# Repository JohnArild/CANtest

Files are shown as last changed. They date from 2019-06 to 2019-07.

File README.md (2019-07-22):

# CANtest

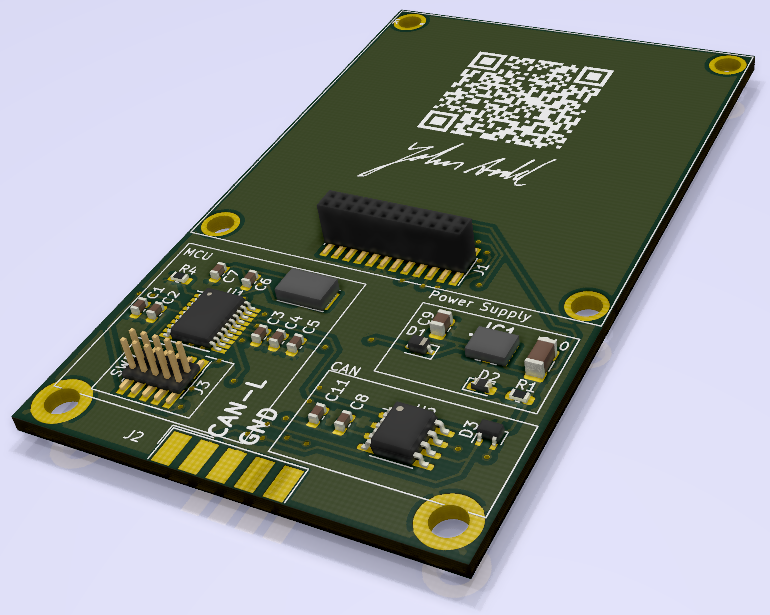
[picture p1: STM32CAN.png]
PCB Render


This project is created to test CAN functionality on STM32
For initial testing, STM32F103C8T6 (Blue Pill) was used.
New board is designed and ordered with STM32F042F6P6. (found in folder kiCad.)

Code is still a mess and just for testing.

Released under BSD License, see file named LICENSE

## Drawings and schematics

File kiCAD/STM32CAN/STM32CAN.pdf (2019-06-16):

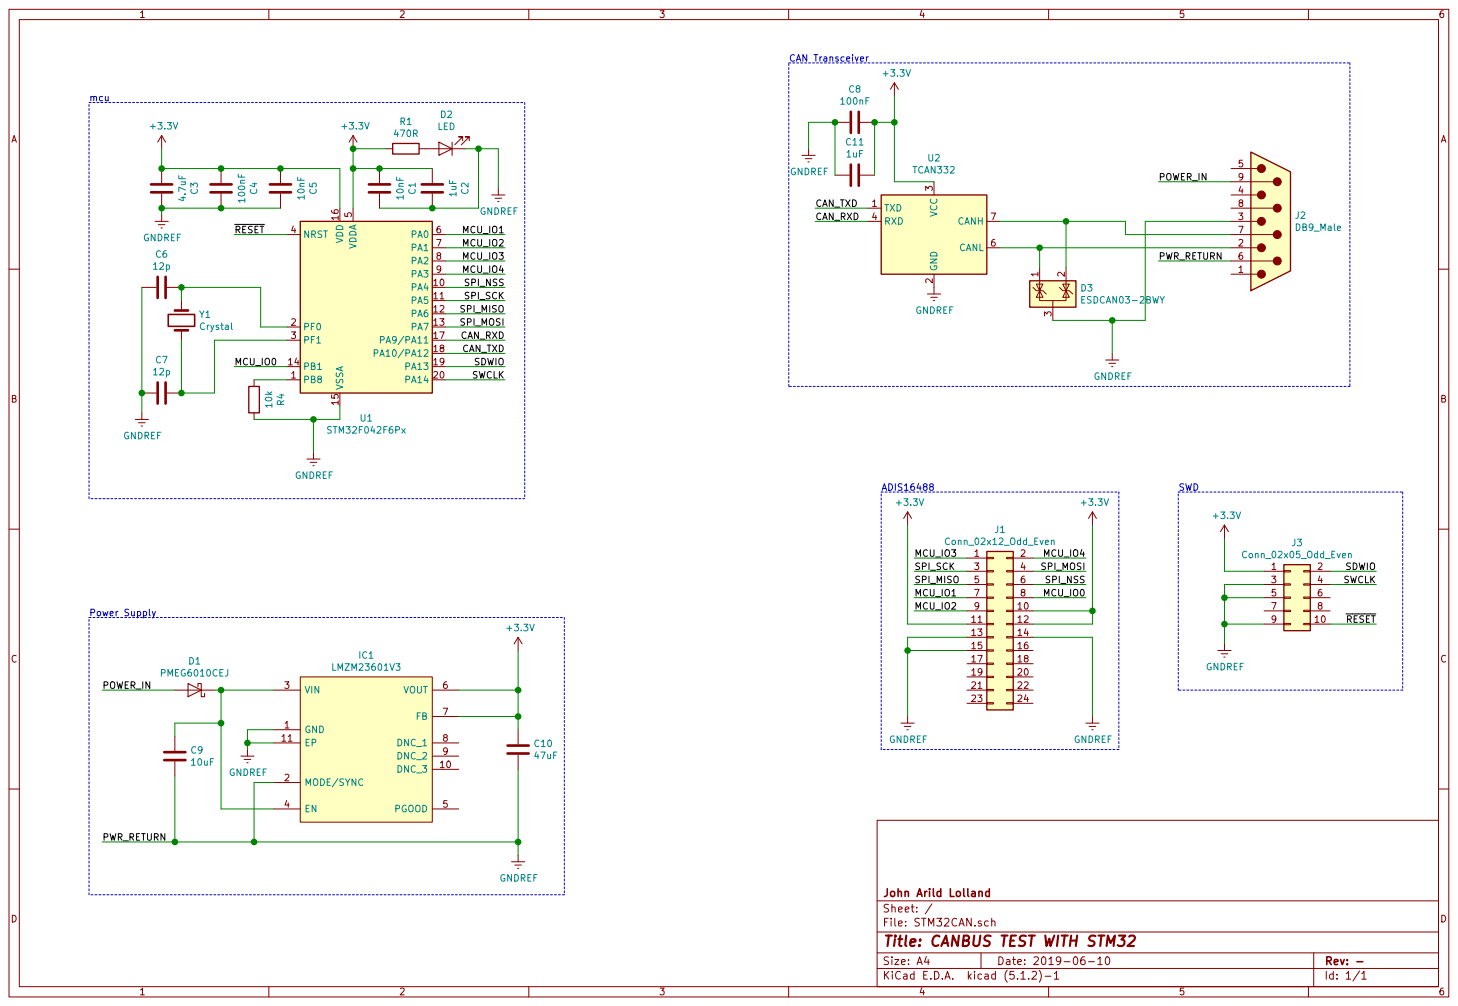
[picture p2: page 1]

3 RXD 4 CANL 6 CANH 7 U2 GNDREF TCAN332 C8

15 | 16
17 | 18

File: STM32CAN.sch Sheet: / John Arild Lolland

Id: 1/1 Title: CANBUS TEST WITH STM32

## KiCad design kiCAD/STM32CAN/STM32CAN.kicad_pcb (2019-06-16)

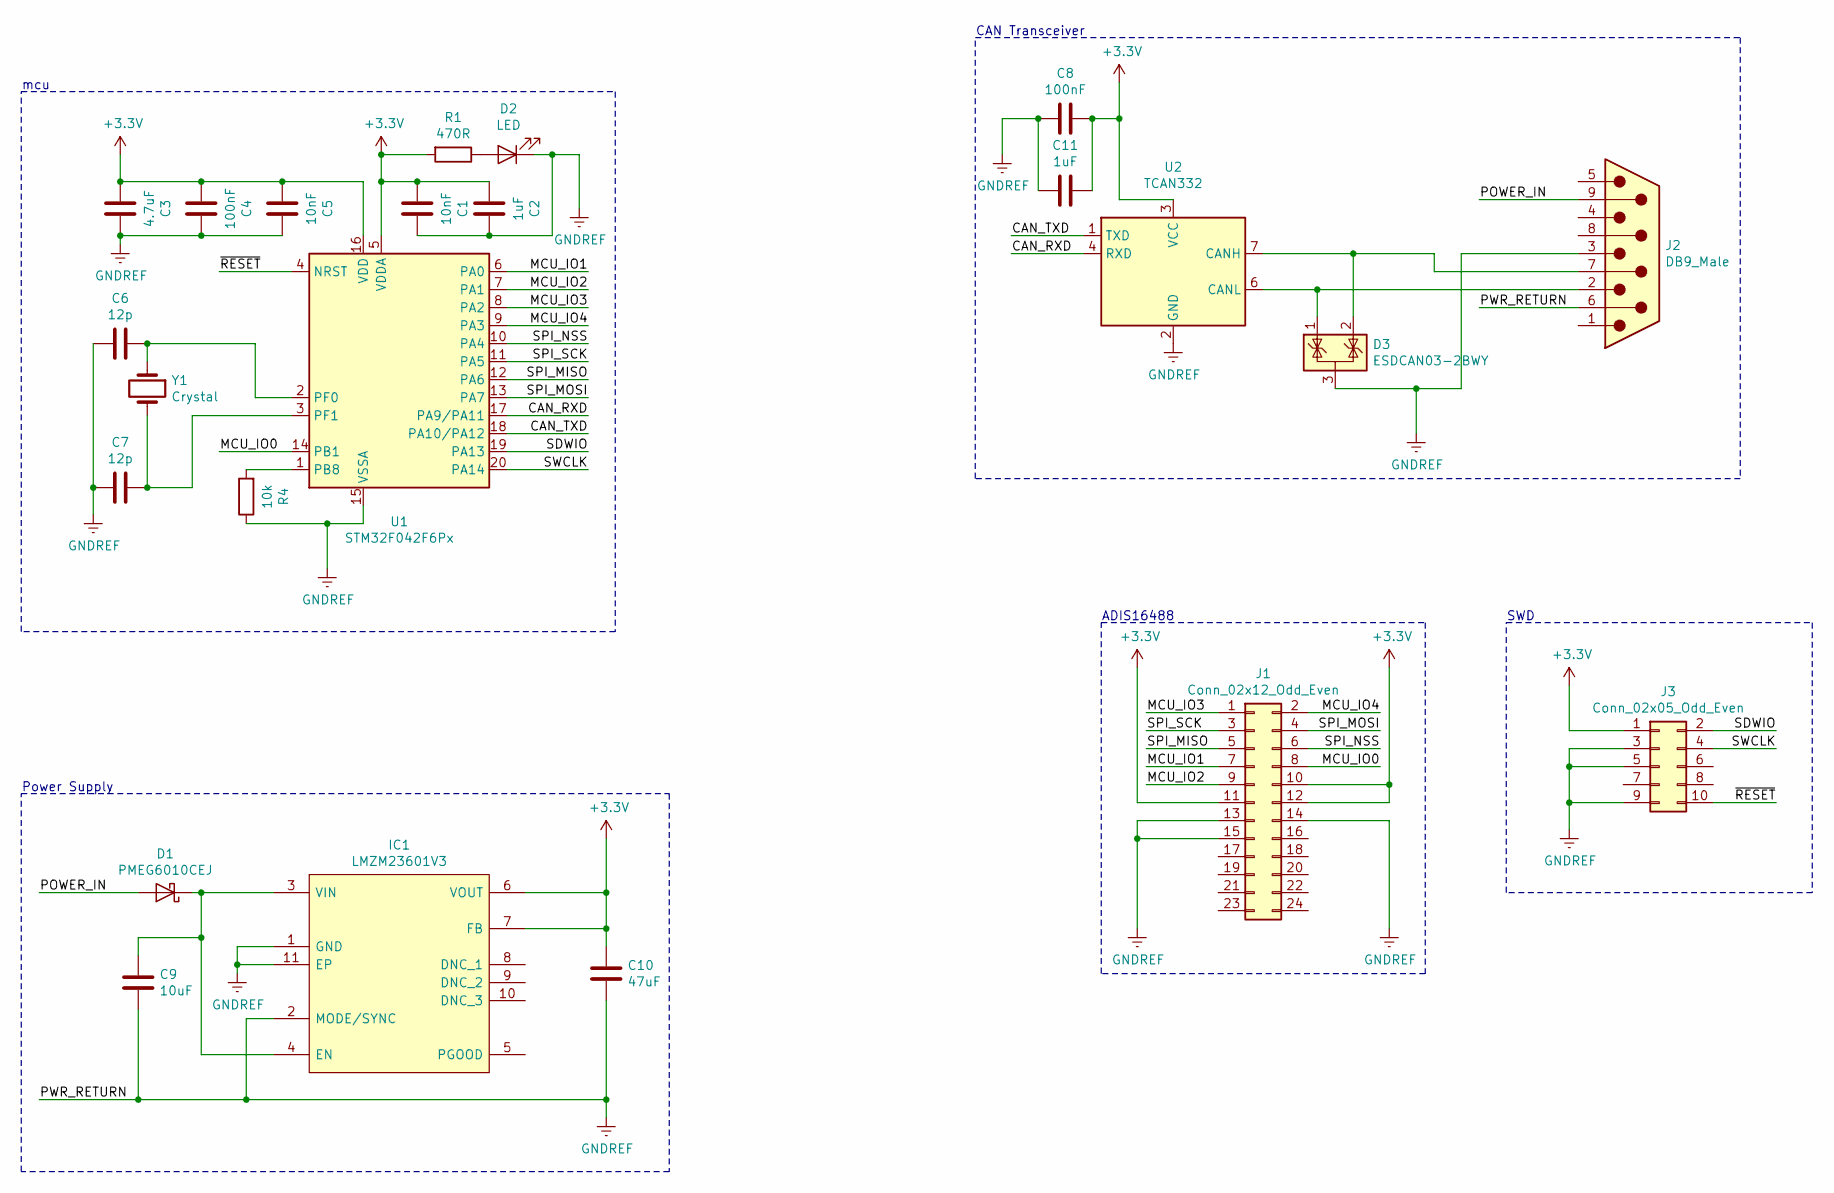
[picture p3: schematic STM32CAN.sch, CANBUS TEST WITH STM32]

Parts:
C1, C5: 10nF; C_0603_1608Metric
C2, C11: 1uF; C_0603_1608Metric
C3: 4.7uF; C_0603_1608Metric
C4, C8: 100nF; C_0603_1608Metric
C6, C7: 12p; C_0603_1608Metric
C9: 10uF; C_0805_2012Metric
C10: 47uF; C_1206_3216Metric
D1: PMEG6010CEJ; D_SOD-323
D2: LED; D_0603_1608Metric
D3: ESDCAN03-2BWY; SOT-323_SC-70
IC1: LMZM23601V3; LMZM23601V5SILR; Mouser Part Number 595-LMZM23601V5SILT
J1: Conn_02x12_Odd_Even; PinHeader_2x12_P1.27mm_Vertical_SMD
J2: DB9_Male; DSUB-9_Male_Horizontal_P2.77x2.54mm_EdgePinOffset9.40mm
J3: Conn_02x05_Odd_Even; PinHeader_2x05_P1.27mm_Vertical_SMD
R1: 470R; R_0603_1608Metric
R4: 10k; R_0603_1608Metric
U1: STM32F042F6Px; TSSOP-20_4.4x6.5mm_P0.65mm
U2: TCAN332; SOIC-8_3.9x4.9mm_P1.27mm
Y1: Crystal; 7A8000MAAET

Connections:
+3V3: C1.2, C2.2, C3.2, C4.2, C5.2, C8.1, C10.1, C11.1, IC1.6 (VOUT), IC1.7 (FB), J1.10, J1.11, J1.12, J3.1, R1.2, U1.5 (VDDA), U1.16 (VDD), U2.3 (VCC)
/CAN_RXD: U1.17 (PA9/PA11), U2.4 (RXD)
/CAN_TXD: U1.18 (PA10/PA12), U2.1 (TXD)
/MCU_IO0: J1.8, U1.14 (PB1)
/MCU_IO1: J1.7, U1.6 (PA0)
/MCU_IO2: J1.9, U1.7 (PA1)
/MCU_IO3: J1.1, U1.8 (PA2)
/MCU_IO4: J1.2, U1.9 (PA3)
/POWER_IN: D1.2 (A), J2.9
/SDWIO: J3.2, U1.19 (PA13)
/SPI_MISO: J1.5, U1.12 (PA6)
/SPI_MOSI: J1.4, U1.13 (PA7)
/SPI_NSS: J1.6, U1.10 (PA4)
/SPI_SCK: J1.3, U1.11 (PA5)
/SWCLK: J3.4, U1.20 (PA14)
/~RESET: J3.10, U1.4 (NRST)
GNDREF: C1.1, C2.1, C3.1, C4.1, C5.1, C6.2, C7.2, C8.2, C9.2, C10.2, C11.2, D2.1 (K), D3.3 (A), IC1.1 (GND), IC1.2 (MODE/SYNC), IC1.11 (EP), J1.13, J1.14, J1.15, J2.3, J2.6, J3.3, J3.5, J3.9, R4.1, U1.15 (VSSA), U2.2 (GND); also elsewhere on the board
unnamed: C6.1, U1.2 (PF0), Y1.1
unnamed: C7.1, U1.3 (PF1), Y1.2
unnamed: C9.1, D1.1 (K), IC1.3 (VIN), IC1.4 (EN)
unnamed: D2.2 (A), R1.1
unnamed: D3.1 (K), J2.2, U2.6 (CANL)
unnamed: D3.2 (K), J2.7, U2.7 (CANH)
unnamed: R4.2, U1.1 (PB8)

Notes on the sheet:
mcu
ADIS16488
SWD
CAN Transceiver
Power Supply

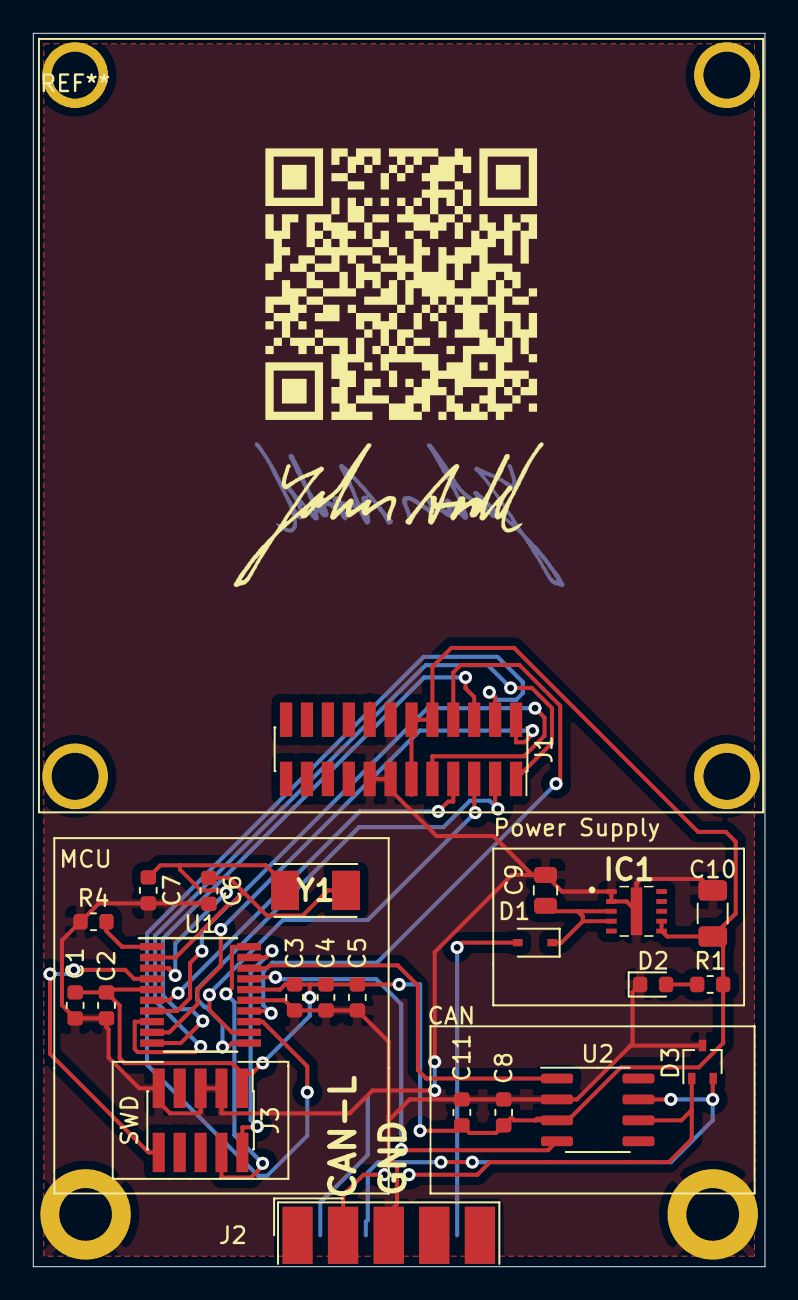
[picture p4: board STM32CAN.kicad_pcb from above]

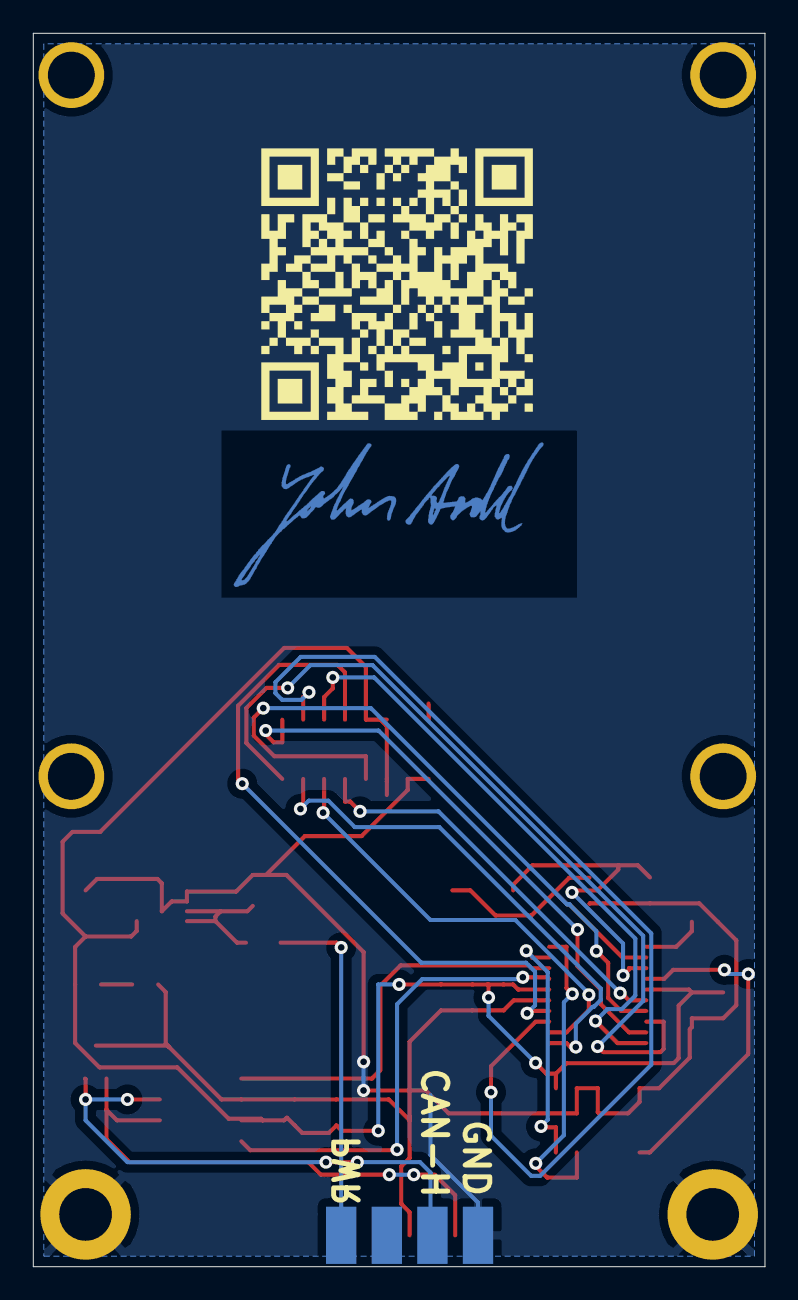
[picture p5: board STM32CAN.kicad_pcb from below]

Board: 2 copper layers, 44.5 x 74.9 mm, 29 parts (2 on the bottom side), 24 nets.

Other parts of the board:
GG1: LOGO; sign-small-Cu
GG2: LOGO; sign-small
Pad1, Pad2: MountingHole_3.2mm_M3_ISO14580_Pad
QR1, QR2: QR_CANtest

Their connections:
GNDREF: Pad1.GNDREF, Pad2.GNDREF; also elsewhere on the board

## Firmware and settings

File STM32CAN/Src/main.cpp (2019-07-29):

/**
  ******************************************************************************
  * @file    main.cpp
  * @author  John Arild Lolland
  ******************************************************************************
*/

#include "BSP.h"

void waitLoop(int loops)
{
	for(int i = 0; i < loops; i++)
	{
		for(uint32_t j = 0; j < 0xFFF; j++)
		{
			;
		}
	}
}

int main(void)
{
	BSP_STM32CAN bsp;

	bsp.initilize();

	while(1)
	{
		GPIOA->BSRR |= GPIO_BSRR_BR_3;
		waitLoop(0xFE);
		GPIOA->BSRR |= GPIO_BSRR_BS_3;
		waitLoop(0xFE);
	}

	return 0;
}

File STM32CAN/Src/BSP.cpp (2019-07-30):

/**
  ******************************************************************************
  * @file    BSP.cpp
  * @author  John Arild Lolland
  ******************************************************************************
*/

#include "BSP.h"

int BSP_STM32CAN::initilize (){
    BSP_STM32CAN::MCUspeed_48MHz();
	BSP_STM32CAN::setup_GPIO ();
	BSP_STM32CAN::setup_CAN ();
	BSP_STM32CAN::setup_SPI ();
    return 0;
}

int BSP_STM32CAN::MCUspeed_48MHz (){
	FLASH->ACR |= FLASH_ACR_LATENCY; // One wait-state for 48MHz operation
	FLASH->ACR |= FLASH_ACR_PRFTBE; // Prefetch buffer enable
	RCC->AHBENR |= RCC_AHBENR_GPIOFEN; // External crystal is on Port F
	RCC->CFGR |= RCC_CFGR_PLLMUL6; // Set PLL to x6 for 48MHz
	RCC->CFGR |= RCC_CFGR_PLLSRC_HSE_PREDIV; // HSE/PREDIV selected as PLL input clock
	RCC->CR |= RCC_CR_HSEON; // Turn in external clock input
	while(!((RCC->CR & RCC_CR_HSERDY)== RCC_CR_HSERDY)){;} // wait for HSE to be ready
	RCC->CR |= RCC_CR_PLLON;
	while(!((RCC->CR & RCC_CR_PLLRDY)== RCC_CR_PLLRDY)){;} // wait for PLL to be ready
	RCC->CFGR |= RCC_CFGR_SW_PLL; // Select PLL for SYSCLOCK
    return 0;
}

int BSP_STM32CAN::setup_GPIO (){
	//Enable ports
	RCC->AHBENR |= RCC_AHBENR_GPIOAEN;
	RCC->AHBENR |= RCC_AHBENR_GPIOBEN;

	//Set up IO pins
	GPIOB->MODER |= GPIO_MODER_MODER1_0; // MCU_IO0 (output)
	GPIOA->MODER |= GPIO_MODER_MODER0_0; // MCU_IO1 (output)
	GPIOA->MODER |= GPIO_MODER_MODER1_0; // MCU_IO2 (output)
	GPIOA->MODER |= GPIO_MODER_MODER2_0; // MCU_IO3 (output)
	GPIOA->MODER |= GPIO_MODER_MODER3_0; // MCU_IO4 (output)
    return 0;
}

int BSP_STM32CAN::setup_CAN (){
	RCC->AHBENR |= RCC_AHBENR_GPIOAEN;
	RCC->APB2ENR |= RCC_APB2ENR_SYSCFGCOMPEN;
	SYSCFG->CFGR1 |= SYSCFG_CFGR1_PA11_PA12_RMP; // Remap (pin pair PA11/12 mapped instead of PA9/10)
	GPIOA->MODER |= GPIO_MODER_MODER11_1; // CAN_RXD (alternative)
	GPIOA->MODER |= GPIO_MODER_MODER12_1; // CAN_TXD (alternative)
	GPIOA->AFR[1] |= 0x44000U; // Set Port 11 and 12 as AF4 for CAN
	//GPIOA->OTYPER |= GPIO_OTYPER_OT_11;
	//GPIOA->OTYPER |= GPIO_OTYPER_OT_12;
	GPIOA->OSPEEDR |= GPIO_OSPEEDR_OSPEEDR11_0 |GPIO_OSPEEDR_OSPEEDR11_1;
	GPIOA->OSPEEDR |= GPIO_OSPEEDR_OSPEEDR12_0 |GPIO_OSPEEDR_OSPEEDR12_1;
	GPIOA->PUPDR |= GPIO_PUPDR_PUPDR11_0;
	GPIOA->PUPDR |= GPIO_PUPDR_PUPDR12_0;
	RCC->APB1ENR |= RCC_APB1ENR_CANEN;
	CAN->MCR |= CAN_MCR_INRQ; // Initialization Request
	//CAN->BTR |= CAN_BTR_LBKM; // Debug mode
	//CAN->MCR |= CAN_MCR_NART; // No retransmitt

	//Create CAN message for testing:
	uint16_t CAN_ID = 0x123;
	uint32_t TIxR = 0;
	TIxR = (CAN_ID << 21); // move 11bit ID to bit 21-31
	while(!((CAN->MSR & CAN_MSR_INAK) == CAN_MSR_INAK)){;} // Wait for INAK to become ready
	CAN->MCR &= ~(0x00010000); // Let CAN work in debug mode
	CAN->MCR &= ~(CAN_MCR_SLEEP); // Wake CAN
	CAN->MCR |= CAN_MCR_TXFP; // Transmit FIFO priority
	CAN->sTxMailBox[0].TDTR |= 0x4;
	CAN->sTxMailBox[0].TIR = TIxR;
	uint32_t CAN_Data = 0xDEADBEEF;
	CAN->sTxMailBox[0].TDLR = CAN_Data;
	CAN->MCR &= ~(CAN_MCR_INRQ);
	CAN->sTxMailBox[0].TIR |= CAN_TI0R_TXRQ;
    return 0;
}

int BSP_STM32CAN::setup_SPI (){
	RCC->AHBENR |= RCC_AHBENR_GPIOAEN;
	GPIOA->MODER |= GPIO_MODER_MODER4_1; // SPI_NSS (alternative)
	GPIOA->MODER |= GPIO_MODER_MODER5_1; // SPI_SCK (alternative)
	GPIOA->MODER |= GPIO_MODER_MODER6_1; // SPI_MISO (alternative)
	GPIOA->MODER |= GPIO_MODER_MODER7_1; // SPI_MOSI (alternative)
	RCC->APB2ENR |= RCC_APB2ENR_SPI1EN;
    return 0;
}

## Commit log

2019-06-05 Changed to STM32CubeIDE
2019-06-10 added KiCAD files
    [STM32CAN.kicad_pcb, STM32CAN.sch]
2019-06-15 Updated kiCAD drawing
    [STM32CAN.sch]
2019-06-16 Started layout
    [STM32CAN.dsn, STM32CAN.kicad_pcb, STM32CAN.sch]
2019-06-16 Rev.- complete. Board ordered
    [STM32CAN-B_Cu.gbr, STM32CAN-B_Mask.gbr, STM32CAN-B_Paste.gbr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]
2019-06-21 Added render of PCB
2019-06-21 Added PCB info
2019-07-29 Blinky light works at 48MHz PLL from HSE with STM32CAN-Board
